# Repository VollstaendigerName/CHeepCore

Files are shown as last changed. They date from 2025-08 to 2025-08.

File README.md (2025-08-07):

# CHeepCore

A minimalist, ultra-low-cost RISC-V development board based on the CH32V003 series. Designed for embedded hobbyists, students, and low-cost prototyping.

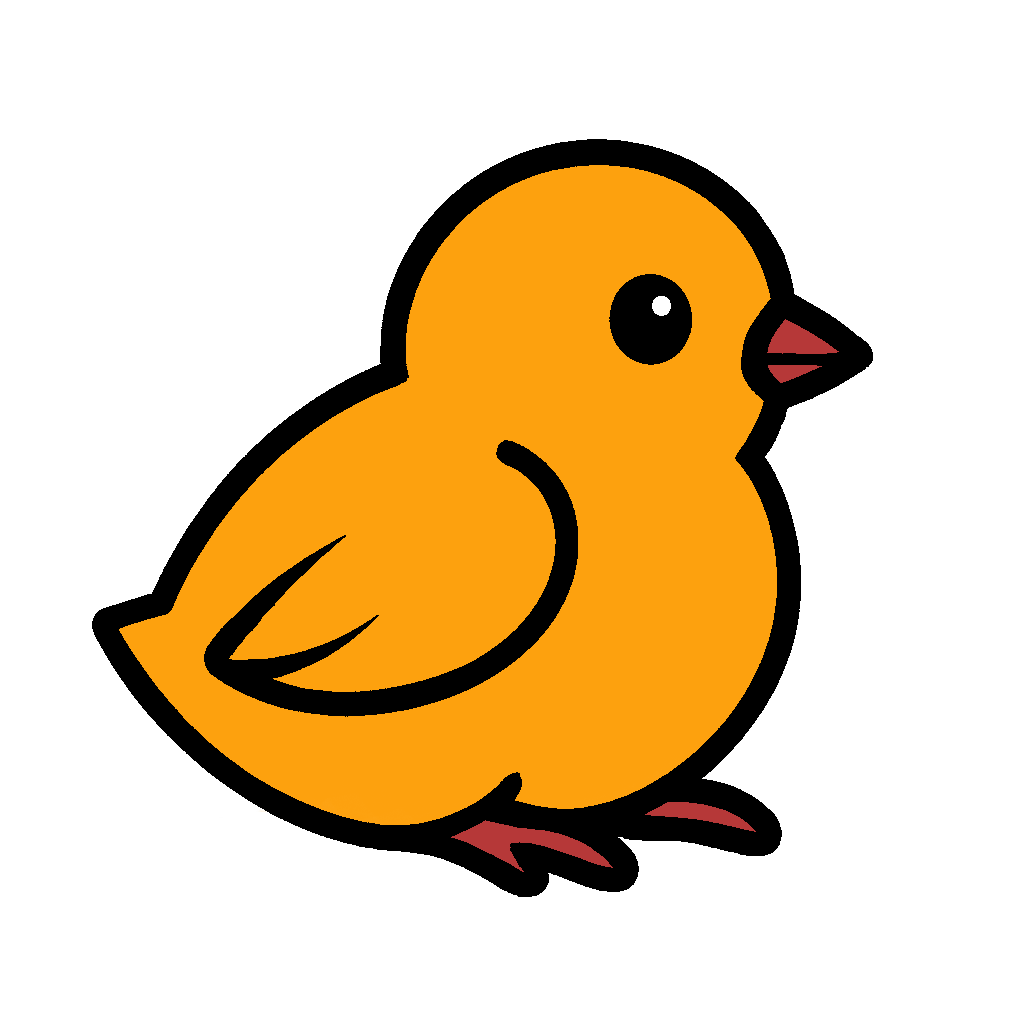
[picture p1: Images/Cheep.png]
CHeepCore Logo


---

## Project Information

- **Name:** CHeepCore  
- **Revision:** 0.0.1b  
- **Date:** 2025-08-06  
- **KiCad Version:** 9.0.3  
- **Target Audience:** Embedded hobbyists, students, low-cost prototyping  
- **Cost Goal:** Complete microcontroller board for under 0.50€  

---

## Key Features

- CH32V003F4U6 32-bit RISC-V microcontroller (20-pin QFN)  
- 16 GPIOs exposed on 2.54 mm headers (PC0–PC7, PD0–PD7)  
- External 24 MHz crystal with 22 pF load capacitors  
- USB-C power input (VBUS → 3.3 V LDO)  
- Configurable solder jumpers for:  
  - USB-VBUS disconnect  
  - 3.3 V / 5 V MCU supply  
- SWD/JTAG programming connectors (3-pin & 10-pin, WCH-LinkE compatible)  
- Breadboard-compatible PCB outline (18.288 × 29.489 mm)  

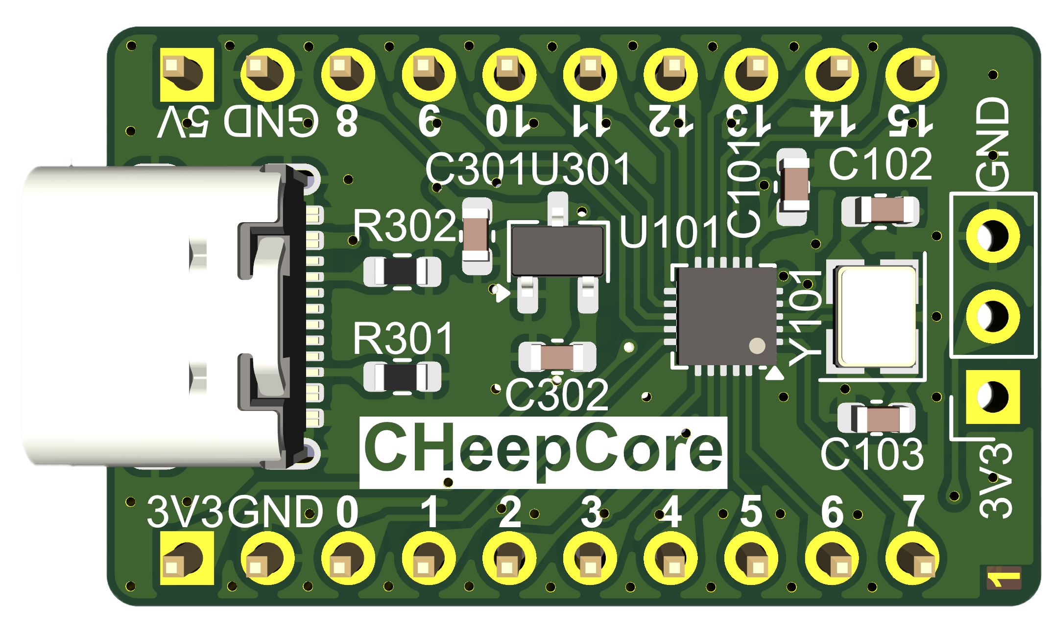
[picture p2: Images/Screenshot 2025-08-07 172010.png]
CHeepCore front


---

## Power Configuration

1. **USB-C Supply**  
   VBUS (5 V) feeds on-board LDO → 3.3 V rail  

2. **External Supply**  
   - Cut the USB-disconnect jumper (bottom side) to isolate VBUS  
   - Inject external 5 V or 3.3 V via header  

3. **MCU Voltage Selection**  
   - Default: 3.3 V  
   - For 5 V operation, cut the 3.3 V jumper (bottom side) and bridge the center pad to 5 V  

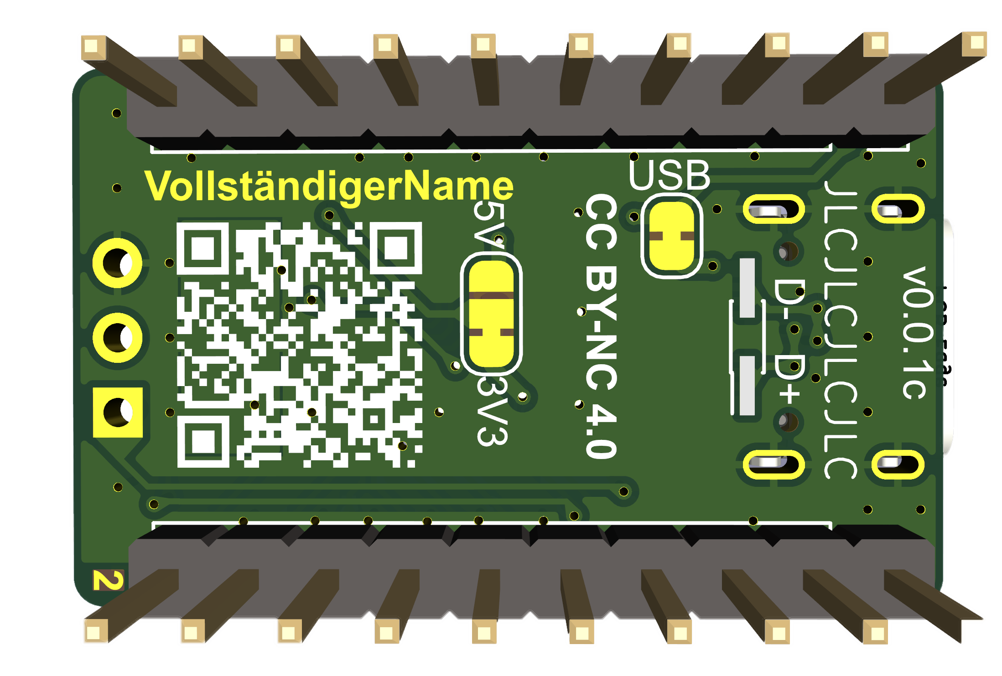
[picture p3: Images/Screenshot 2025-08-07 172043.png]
CHeepCore back


---

## Programming with WCH-LinkE

- Connect **3V3** and **GND** pins  
- Connect **SWDIO/TMS** to the middle pin of the 3-pin header  
- SWCLK/TCK and reset lines available on 10-pin header for full JTAG  

---

## Mechanical Dimensions

- **Width:** 29.489 mm  
- **Height:** 18.288 mm  
- Compatible with standard 2.54 mm breadboards  

---

## GPIO Pinout

| # | Header Pin | Default Function | Alternate Function |
| --- | --- | --- | --- |
| 0 | PD0 | T1CH1N / OPN1 | SDA / UTX |
| 1 | PD1 | SWIO / AETR2 | T1CH3N / SCL / URX |
| 2 | PD2 | A3 / T1CH1 / T2CH3 | T1CH2N |
| 3 | PD3 | A4 / T2CH2 / AETR | UCTS / T1CH4 |
| 4 | PD4 | A7 / UCK / T2CH1ETR | OPO / T1CH4ETR |
| 5 | PD5 | A5 / UTX | T2CH4 / URX |
| 6 | PD6 | A6 / URX | T2CH3 / UTX |
| 7 | PD7 | NRST / T2CH4 | OPP1 / UCK |
| 8 | PC7 | MISO / T1CH2 | T2CH2 / URTS |
| 9 | PC6 | MOSI / T1CH1CH3N | UCTS / SDA |
| 10  | PC5 | SCK / T1ETR / T2CH1ETR | SCL / UCK / T1CH3 |
| 11  | PC4 | A2 / T1CH4 / MCO | T1CH1CH2N |
| 12  | PC3 | T1CH3 / T1CHIN | UCTS |
| 13  | PC2 | SCL / URTS / T1BKIN | AETR / T2CH2 / T1ETR |
| 14  | PC1 | SDA / NSS / T2CH4 | T2CH1ETR / T1BKIN / URX |
| 15  | PC0 | T2CH3 / UTX | NSS / T1CH3 |

---
## Bill of Material (BoM)

| Reference | Qty | Unit Price (€) | Description |
|---|:---:|---:|---|
| C101 |  1  | 0.0020  | YAGEO CC0603KRX7R7BB104 (100 nF, 0603) |
| C102, C103 |  2  | 0.0016  | YAGEO CC0603JRNPO9BN220 (22 pF, 0603) |
| C301, C302 |  2  | 0.0033  | Samsung CL10A105KB8NNNC (1 µF, 0603) |
| J301 |  1  | 0.0300  | SHOU HAN TYPE-C 16-PIN 2MD(073) |
| R301, R302 |  2  | 0.0004  | VO SCR0603J5K1 (5.1 kΩ, 0603) |
| U101 |  1  | 0.1599  | CH32V003F4U6 (32-bit RISC-V microcontroller) |
| U301 |  1  | 0.0047  | Megain MG6206K3B-33 (3.3 V LDO) |
| Y101 |  1  | 0.0323  | TOGNJING XTM32024000DT00351001 (24 MHz crystal) |

---

## Author & License

   VollständigerName  GitHub: https://github.com/VollstaendigerName

   <small><span style="color:lightgrey;">
   This work is licensed under Creative Commons Attribution-NonCommercial 4.0 International (CC BY-NC 4.0). See LICENSE.txt for details.

   This hardware specification and documentation have been prepared to the best of the author’s knowledge, but are provided without any warranty. The author accepts no liability for malfunctions, consequential damages, or any claims arising from the use of this information, the design, or the implemented hardware. Any liability is expressly excluded.
   </span></small>

## Repository Contents

```text
/
├── CHeepCore/       # KiCad schematic and PCB files
├── Images/          # Images of the 3d Model
├── production/      # Gerber export for fabrication   
├── README.md        # This file  
└── LICENSE.txt      # CC BY-NC 4.0

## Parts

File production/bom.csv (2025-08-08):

Designator | Footprint | Quantity | Value | LCSC Part #
C101 | 0603 | 1 | 100nF | https://www.lcsc.com/product-detail/C108079.html?s_z=n_CC0603KRX7R7BB104
C102, C103 | 0603 | 2 | 22pF | https://www.lcsc.com/product-detail/C105620.html
C301, C302 | 0603 | 2 | 1µF | https://www.lcsc.com/product-detail/C15849.html
J101, J102 | PinSocket_1x10_P2.54mm_Vertical | 2 | Conn_01x10
J103 | PinHeader_2x01_P1.00mm_Vertical_SMD | 1 | USB
J201 | PinSocket_1x03_P2.54mm_Vertical | 1 | Conn_01x03
J301 | USB_C_Receptacle_GCT_USB4105-xx-A_16P_TopMnt_Horizontal | 1 | USB_C_Receptacle_USB2.0_16P | https://www.lcsc.com/product-detail/C2765186.html?s_z=n_USB%2520C
R301, R302 | 0603 | 2 | 5k1 | https://www.lcsc.com/product-detail/C3017721.html
U101 | QFN-20-1EP_3x3mm_P0.4mm_EP1.65x1.65mm | 1 | CH32V003FxUx | https://www.lcsc.com/product-detail/C5299908.html?s_z=n_CH32v003
U301 | TSOT-23 | 1 | 3V3 LDO | https://www.lcsc.com/product-detail/C48678136.html
Y101 | Crystal_SMD_3225-4Pin_3.2x2.5mm | 1 | Crystal_GND24 | https://www.lcsc.com/product-detail/C41383243.html?s_z=n_24Mhz

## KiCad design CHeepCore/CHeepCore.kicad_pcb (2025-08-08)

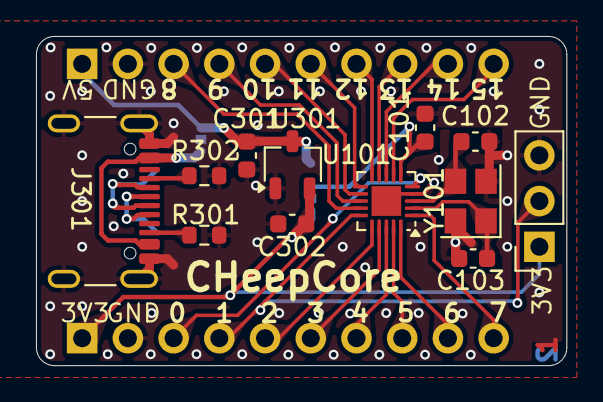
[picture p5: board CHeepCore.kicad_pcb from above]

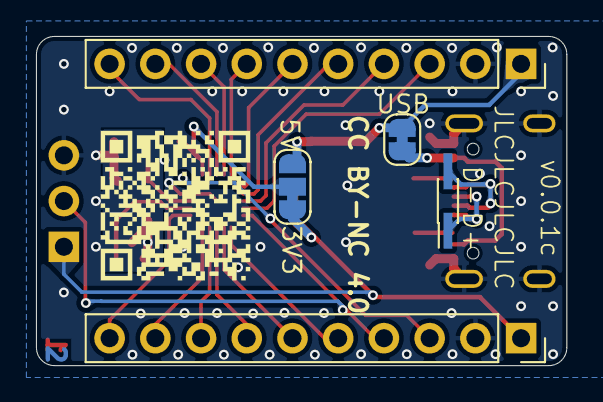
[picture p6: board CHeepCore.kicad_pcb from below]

Board: 2 copper layers, 29.5 x 18.3 mm, 17 parts (5 on the bottom side), 27 nets.

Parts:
C101: 100nF; C_0603_1608Metric
C102, C103: 22pF; C_0603_1608Metric
C301, C302: 1µF; C_0603_1608Metric
J101, J102: Conn_01x10; PinSocket_1x10_P2.54mm_Vertical
J103: USB; PinHeader_2x01_P1.00mm_Vertical_SMD
J201: Conn_01x03; PinSocket_1x03_P2.54mm_Vertical
J301: USB_C_Receptacle_USB2.0_16P; USB_C_Receptacle_GCT_USB4105-xx-A_16P_TopMnt_Horizontal
JP101: 3V3 or 5V; SolderJumper-3_P1.3mm_Bridged12_RoundedPad1.0x1.5mm_NumberL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
JP301: USB Disconnect; SolderJumper-2_P1.3mm_Bridged_RoundedPad1.0x1.5mm
R301, R302: 5k1; R_0603_1608Metric
U101: CH32V003FxUx; QFN-20-1EP_3x3mm_P0.4mm_EP1.65x1.65mm
U301: 3V3 LDO; TSOT-23
Y101: Crystal_GND24; Crystal_SMD_3225-4Pin_3.2x2.5mm

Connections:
+3V3: C302.1, J102.1, J201.1, JP101.1 (A), U301.2 (VO)
+5V: C301.1, J101.1, JP101.3 (B), JP301.2 (B), U301.3 (VI)
/PC0: J101.10, U101.7 (PC0)
/PC1: J101.9, U101.8 (PC1)
/PC2: J101.8, U101.9 (PC2)
/PC3: J101.7, U101.10 (PC3)
/PC4: J101.6, U101.11 (PC4)
/PC5: J101.5, U101.12 (PC5)
/PC6: J101.4, U101.13 (PC6)
/PC7: J101.3, U101.14 (PC7)
/PD0: J102.3, U101.5 (PD0)
/PD1: J102.4, J201.2, U101.15 (PD1)
/PD2: J102.5, U101.16 (PD2)
/PD3: J102.6, U101.17 (PD3)
/PD4: J102.7, U101.18 (PD4)
/PD5: J102.8, U101.19 (PD5)
/PD6: J102.9, U101.20 (PD6)
/PD7: J102.10, U101.1 (PD7)
/USB with LDO/D+: J103.1, J301.A6 (D+), J301.B6 (D+)
/USB with LDO/D-: J103.2, J301.A7 (D-), J301.B7 (D-)
GND: C101.2, C102.2, C103.2, C301.2, C302.2, J101.2, J102.2, J201.3, J301.A1 (GND), J301.A12 (GND), J301.B1 (GND), J301.B12 (GND), J301.S1 (SHIELD), R301.2, R302.2, U101.4 (VSS), U101.21 (VSS), U301.1 (GND), Y101.2, Y101.4
unnamed: J301.A5 (CC1), R302.1
unnamed: J301.B5 (CC2), R301.1
unnamed: C101.1, JP101.2 (C), U101.6 (VDD)
unnamed: J301.A4 (VBUS), J301.A9 (VBUS), J301.B4 (VBUS), J301.B9 (VBUS), JP301.1 (A)
unnamed: C103.1, U101.2 (PA1), Y101.1
unnamed: C102.1, U101.3 (PA2), Y101.3

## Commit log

2025-08-07 Changed Via size
    JLCPCB charges more for smaller vias. Therefore, vias are enlarged to save PCB costs.
2025-08-07 Changed Via size
    JLCPCB charges more for smaller vias. Therefore, vias are enlarged to save PCB costs. Now only 2€ for 5 PCBs
    [CHeepCore.kicad_pcb]
2025-08-07 Update README.md
    added BOM
2025-08-08 Added USB to smd pad
    USB smd pads added on the back
    [CHeepCore.kicad_pcb, CHeepCore.kicad_sch, USB-C_LDO.kicad_sch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]
2025-08-08 Update Production Files
    with USB pads on the back
    [bom.csv, designators.csv, positions.csv]

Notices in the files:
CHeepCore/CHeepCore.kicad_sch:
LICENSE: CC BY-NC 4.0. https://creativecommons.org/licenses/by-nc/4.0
